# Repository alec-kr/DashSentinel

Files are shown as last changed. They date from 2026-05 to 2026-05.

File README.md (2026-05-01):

# 🚗 DashSentinel

**Real-time Driver Drowsiness Detection System with Embedded Feedback Interface**

<table align="center">
  <tr>
    <td align="center">
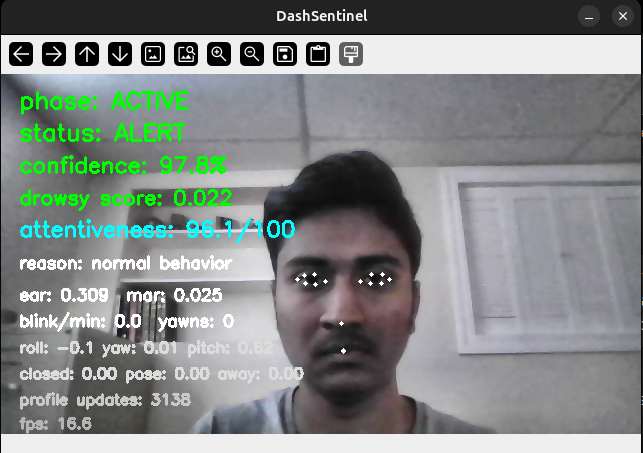
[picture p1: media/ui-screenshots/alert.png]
      <br>
      <b>Left:</b> Real-time facial tracking and attentiveness scoring
    </td>
    <td align="center">
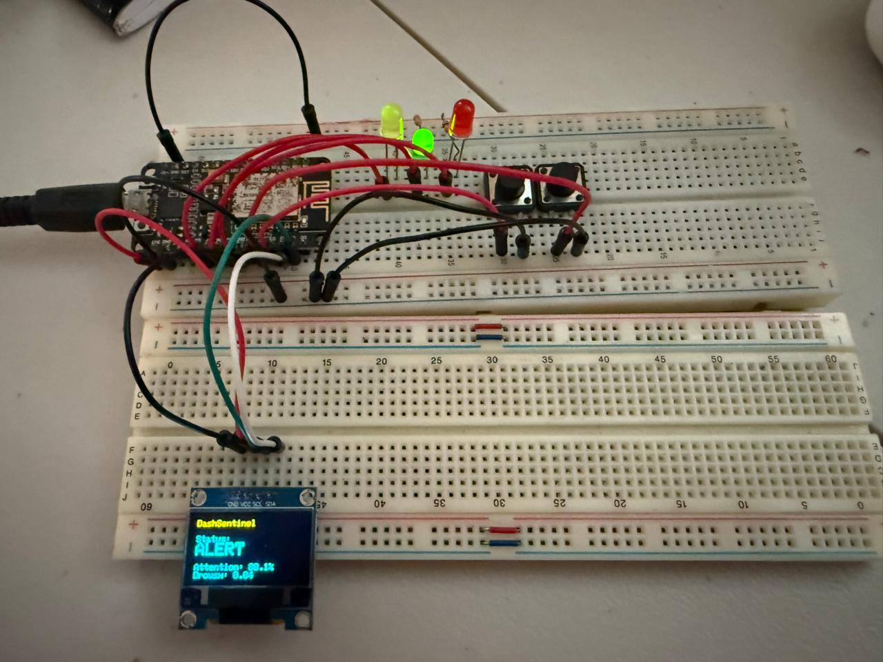
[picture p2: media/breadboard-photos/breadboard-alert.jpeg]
      <br>
      <b>Right:</b> ESP8266 hardware interface
    </td>
  </tr>
</table>

## Overview

The system combines:

- Computer Vision (MediaPipe / OpenCV) for facial feature extraction
- Machine Learning / Heuristics for drowsiness classification
- Embedded System (ESP8266) for real-time display and user interaction

It is designed as a prototype for a deployable driver safety product in fleets/personal use.

## Features
- Real-time face tracking and feature extraction
- Driver attentiveness scoring (%)
- Drowsiness detection based on:
    - eye closure patterns
    - yawning detection
    - attentiveness %

- OLED display output:
    - status (ALERT / WARNING / DROWSY)

- LED indicators:
    - 🟢 ALERT → solid green
    - 🟡 WARNING → blinking yellow
    - 🔴 DROWSY → fast blinking red

- Physical buttons:
    - Reset baseline (user-specific calibration)
    - Reset stats (data stored over-time)

## Tech Stack
### 💾 Software
- Python 3
- OpenCV
- MediaPipe
- TensorFlow (optional for model extensions)
- PySerial

### ⚙️ Hardware
- ESP8266 (NodeMCU)
- SSD1306 OLED (I2C, 128x64)
- Push buttons (x2)
- LEDs (red, yellow, green)
- Resistors (3x 330 ohms)

## 📁 Project Structure

```text

DashSentinel/
├── run_dashsentinel.py        # main entrypoint for execution
│
├── src/                       # core application logic
│   ├── app.py                 # main app orchestration
│   ├── features.py            # feature extraction (ear, yawning, etc.)
│   ├── model.py               # scoring / detection logic
│   └── serial.py              # esp8266 communication layer
│
├── DisplayModule/             # esp8266 firmware (platformio project)
│   └── src/
│       └── main.cpp           # oled, leds, buttons logic
│
├── nodemcu_carrier_pcb/       # hardware design (KiCad)
|
├── schematic/                 # schematic for all connections
│
├── data/                      # runtime-generated data
│   └── driver_profile.json    # user-specific baseline + stats
|
├── media/                     # Images showing the system in operation
│
├── requirements.txt           # python dependencies
└── README.md                  # project documentation

```

## Install requirements
```bash
pip install -r requirements.txt
```

## ▶️ Run the Project

### With UI and ESP8266 Interface
```bash
python3 run_dashsentinel.py --show-ui --draw-landmarks --enable-esp-serial --esp-port /dev/ttyUSB0
```

### Headless mode (logging enabled)
```bash
python3 run_dashsentinel.py --headless --log-csv --enable-esp-serial --esp-port /dev/ttyUSB0
```

### Optional flags (see ```src/cli.py``` for full list of options)
```bash
python3 run_dashsentinel.py --show-ui --draw-landmarks --refine-landmarks
```

## Startup Calibration
At startup:
- system learns user-specific facial metrics
- establishes baseline EAR and behavior

## Reset options
- Hardware button → reset baseline
- CLI flag → rebuild baseline at launch

```bash
python3 run_dashsentinel.py --show-ui --mirror --rebuild-baseline-on-start
```

## 🚀 Future Improvements
- Replace heuristic model with trained ML model
- Mobile app integration
- Full standalone embedded unit (dashcam form factor)

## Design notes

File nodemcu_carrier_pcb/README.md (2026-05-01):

## NodeMCU ESP-12E carrier board for DashSentinel external display/status module.

Features:
- Amica-style NodeMCU ESP-12E footprint, 22.86 mm / 0.9 in header spacing
- 4-pin I2C OLED connector: GND, VCC, SCL, SDA
- 3 status LEDs: green/yellow/red
- 2 push buttons
- Through-hole components for easy hand soldering

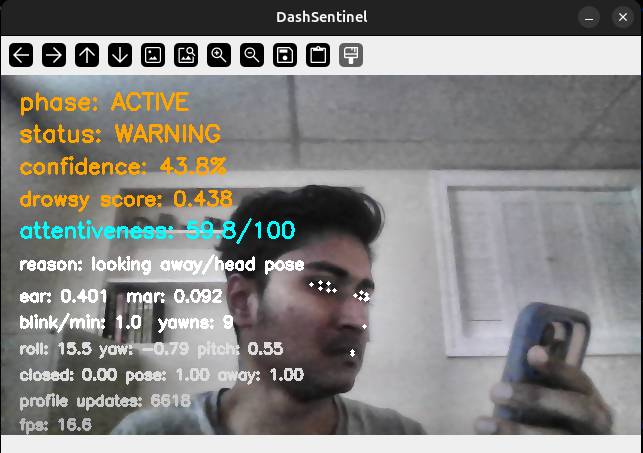
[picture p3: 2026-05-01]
media/ui-screenshots/warning-looking-away.png

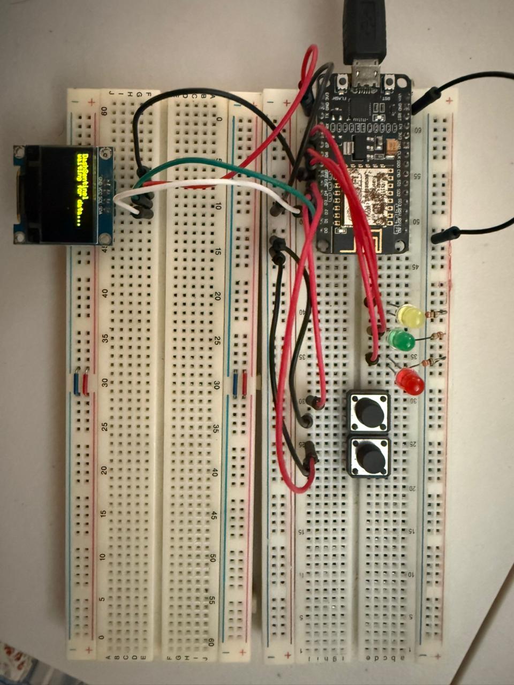
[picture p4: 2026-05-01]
media/breadboard-photos/breadboard-top-view.jpeg

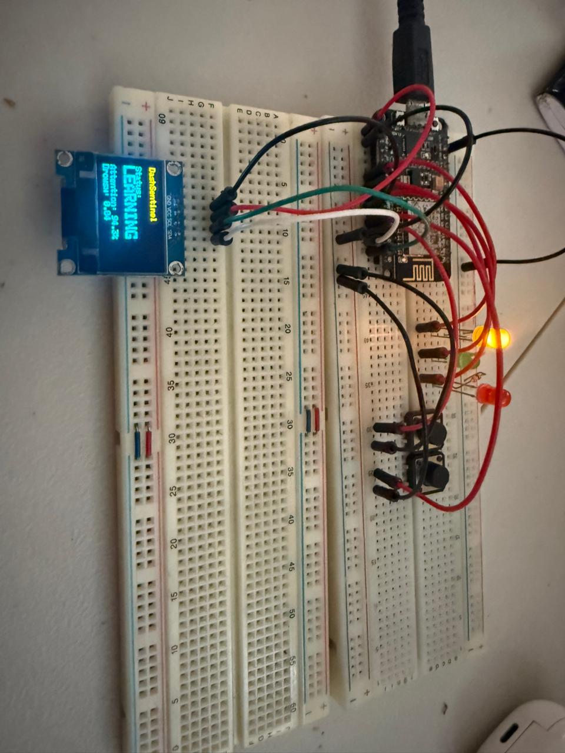
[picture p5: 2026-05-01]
media/breadboard-photos/breadboard-learning.jpeg

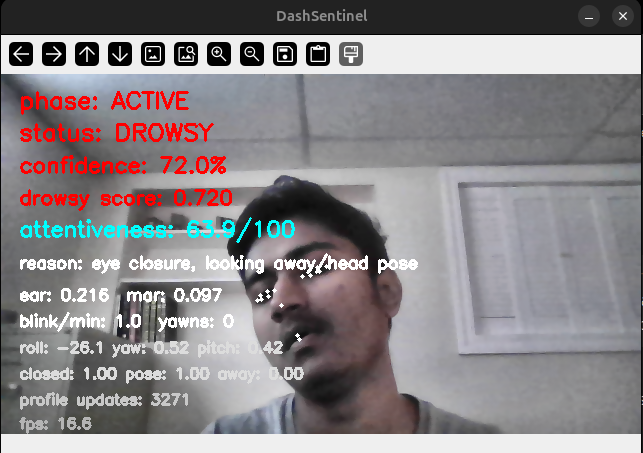
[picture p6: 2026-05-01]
media/ui-screenshots/drowsy-looking-away-eyes-closed.png

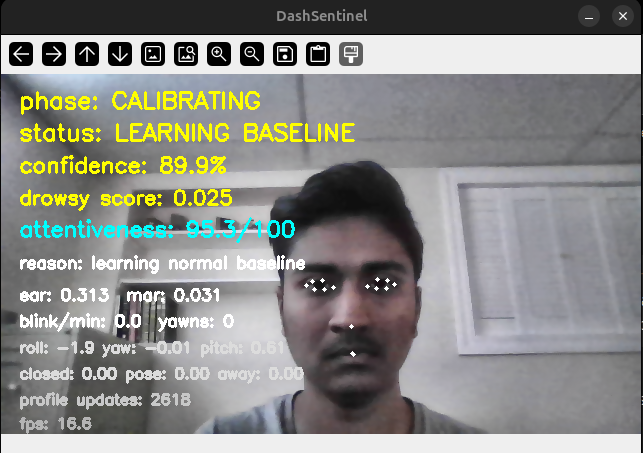
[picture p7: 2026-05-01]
media/ui-screenshots/learning_baseline.png

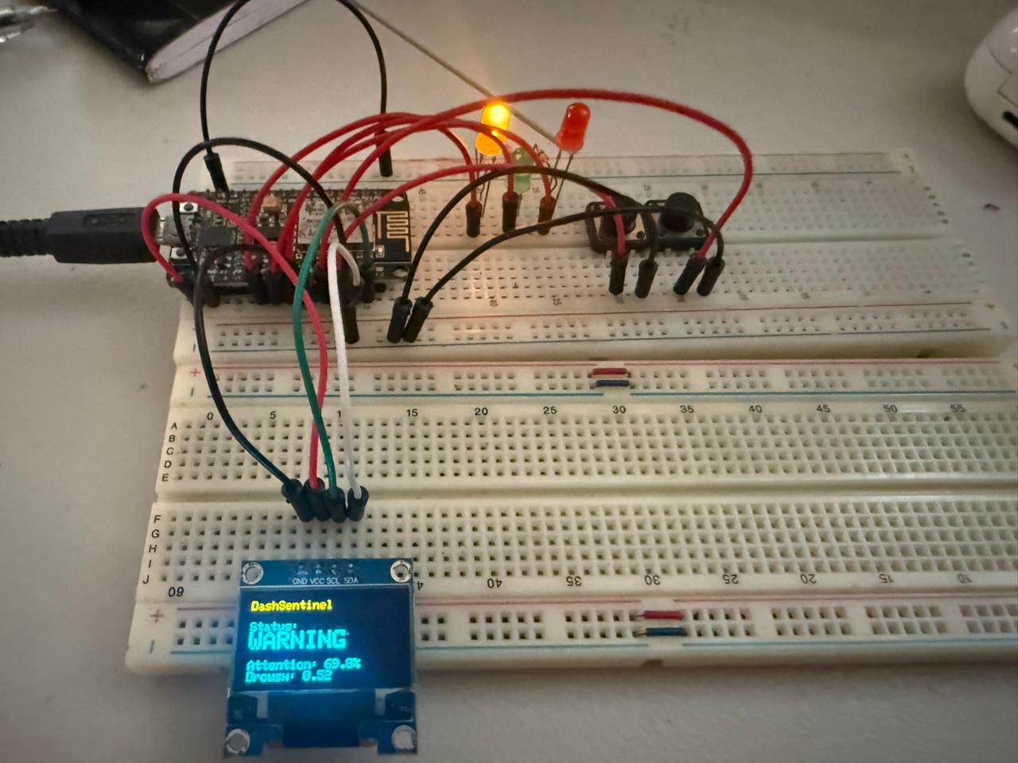
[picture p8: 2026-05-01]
media/breadboard-photos/breadboard-warning.jpeg

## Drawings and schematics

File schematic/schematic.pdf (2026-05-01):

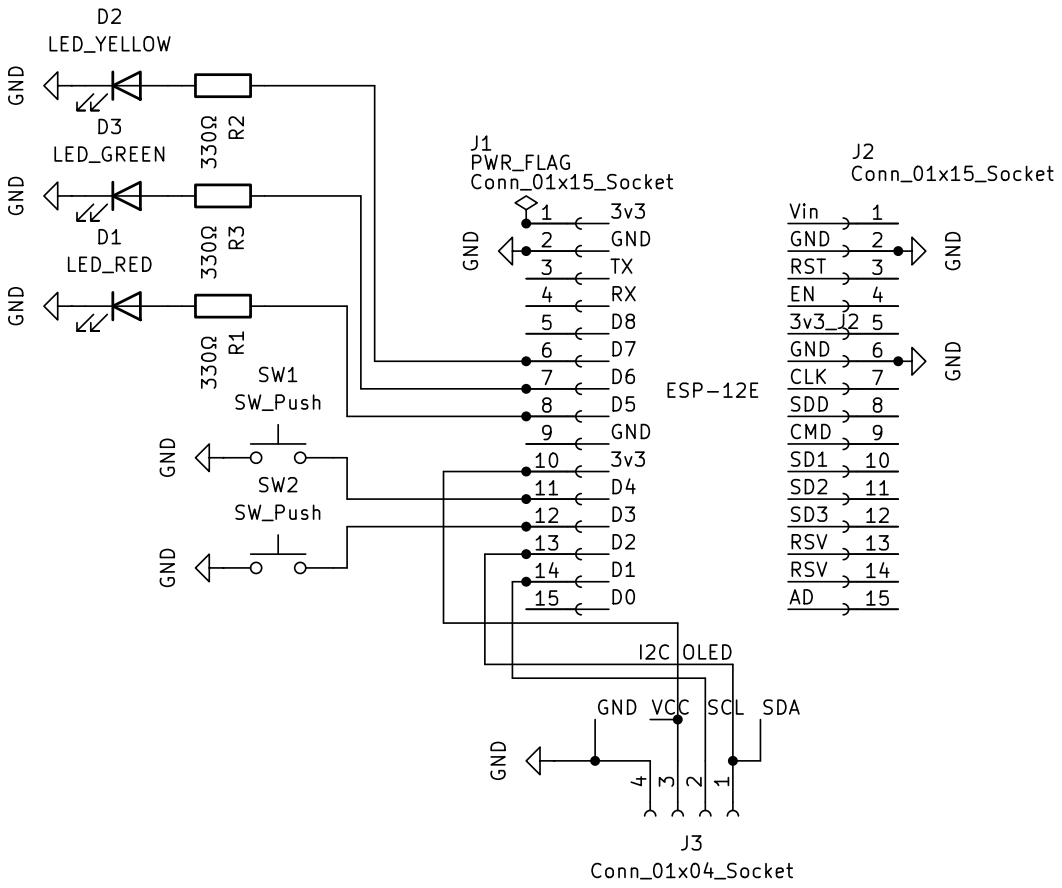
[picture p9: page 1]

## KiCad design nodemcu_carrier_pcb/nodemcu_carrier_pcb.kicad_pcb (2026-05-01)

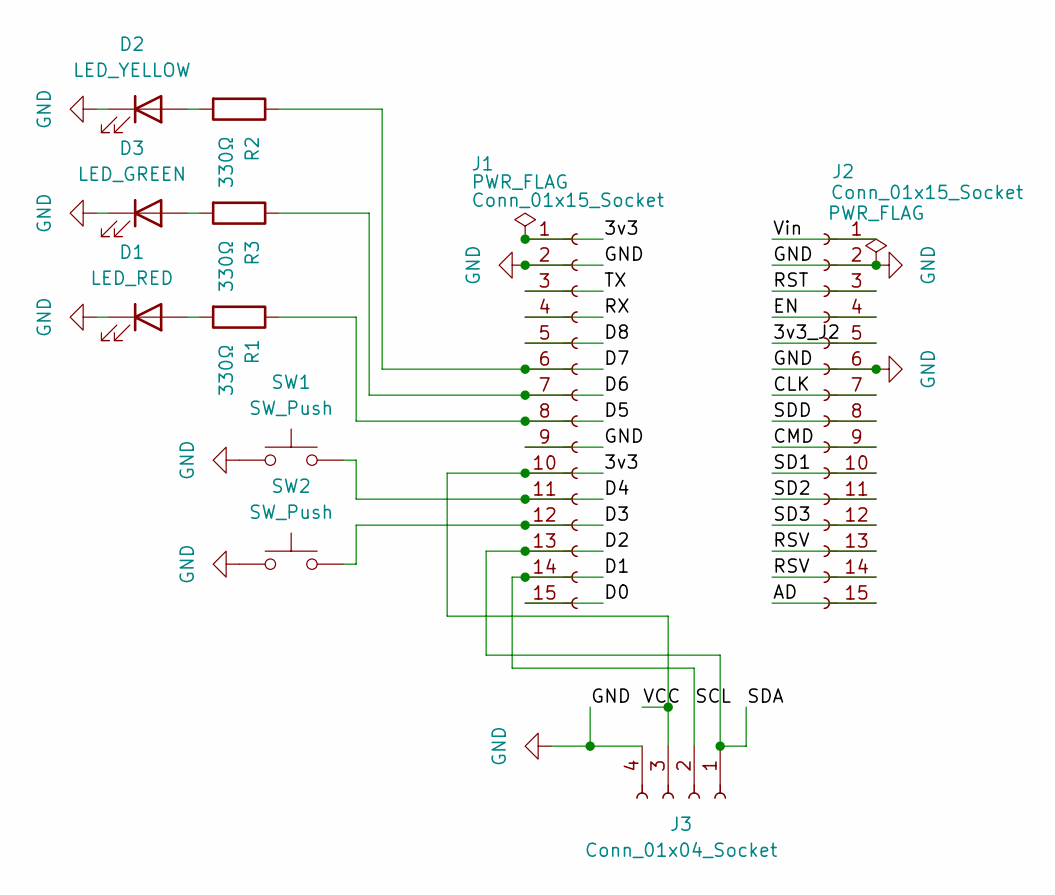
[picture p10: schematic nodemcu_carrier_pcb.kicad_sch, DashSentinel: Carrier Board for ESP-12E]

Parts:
D1: LED_RED; LED_D3.0mm
D2: LED_YELLOW; LED_D3.0mm
D3: LED_GREEN; LED_D3.0mm
J1, J2: Conn_01x15_Socket; PinSocket_1x15_P2.54mm_Vertical
J3: Conn_01x04_Socket; PinSocket_1x04_P2.54mm_Vertical
R1, R2, R3: 330Ω; R_Axial_DIN0207_L6.3mm_D2.5mm_P7.62mm_Horizontal
SW1, SW2: SW_Push; SW_PUSH_6mm

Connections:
/3v3: J1.1, J1.10, J3.3
/3v3_J2: J2.5
/AD: J2.15
/CLK: J2.7
/CMD: J2.9
/D0: J1.15
/D1: J1.14, J3.2
/D2: J1.13, J3.1
/D3: J1.12, SW2.2
/D4: J1.11, SW1.2
/D5: J1.8, R1.1
/D6: J1.7, R3.1
/D7: J1.6, R2.1
/D8: J1.5
/EN: J2.4
/RST: J2.3
/RSV: J2.13, J2.14
/RX: J1.4
/SD1: J2.10
/SD2: J2.11
/SD3: J2.12
/SDD: J2.8
/TX: J1.3
/Vin: J2.1
GND: D1.1 (K), D2.1 (K), D3.1 (K), J1.2, J1.9, J2.2, J2.6, J3.4, SW1.1, SW2.1
unnamed: D1.2 (A), R1.2
unnamed: D2.2 (A), R2.2
unnamed: D3.2 (A), R3.2

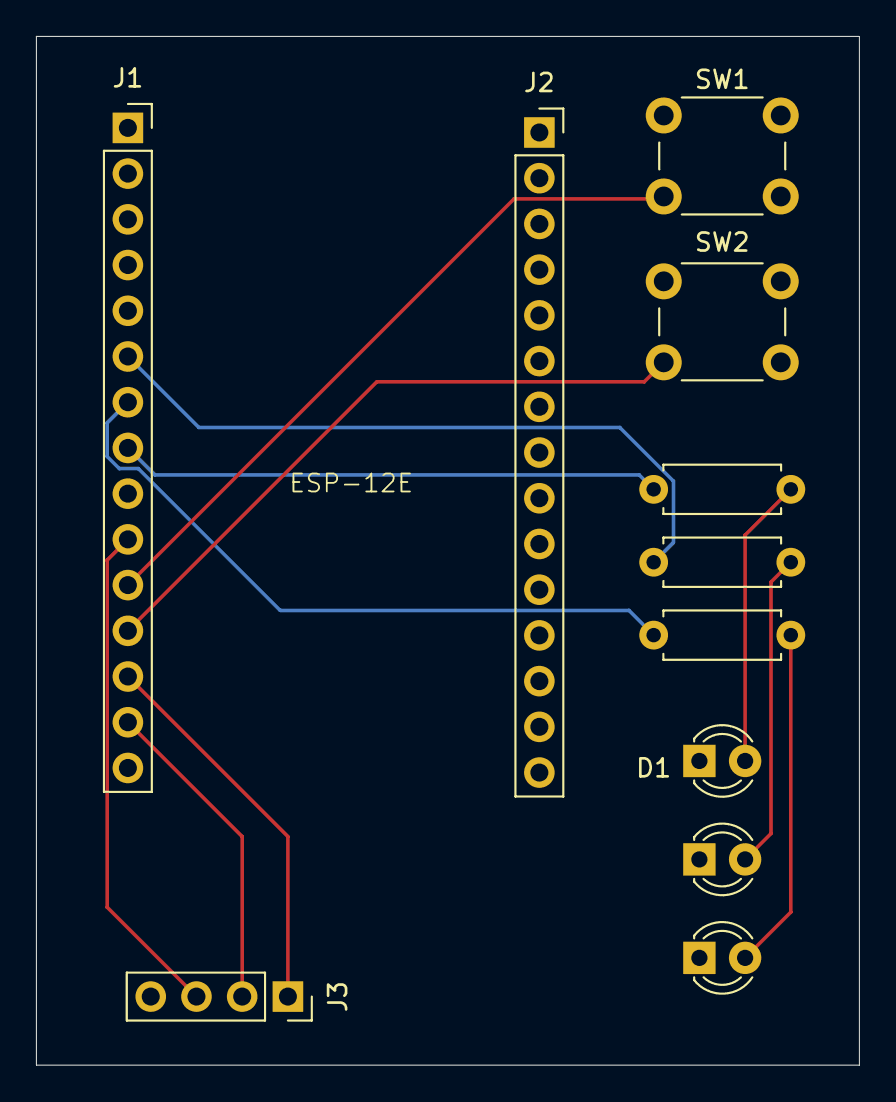
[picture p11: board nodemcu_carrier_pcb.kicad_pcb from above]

Board: 2 copper layers, 45.7 x 57.2 mm, 11 parts (0 on the bottom side), 13 nets.

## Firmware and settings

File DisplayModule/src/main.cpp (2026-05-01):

#include <Arduino.h>
#include <Wire.h>
// required for display
#include <Adafruit_GFX.h>
#include <Adafruit_SSD1306.h>

// init oled dimensions
#define SCREEN_WIDTH 128
#define SCREEN_HEIGHT 64
#define OLED_RESET -1

// define pins for buttons
#define BTN_RESET_BASELINE D3 // to reset the baseline for drowsiness detection
#define BTN_RESET_STATS D4 // to reset the drowsiness score and attentiveness score

#define redPin D5
#define greenPin D6
#define yellowPin D7

// i2c address for ssd1306
#define OLED_ADDR 0x3C

// display object
Adafruit_SSD1306 display(SCREEN_WIDTH, SCREEN_HEIGHT, &Wire, OLED_RESET);

// store current status and scores
String currentStatus = "NO DATA";
float attentiveness = 0.0;
float drowsyScore = 0.0;

// store last button states
bool lastBaselineState = HIGH;
bool lastStatBtnState = HIGH;

// store last button press times for debouncing
unsigned long lastBaselinePress = 0;
unsigned long lastStatBtnPress = 0;
const unsigned long debounceMs = 250;

// led state modes
enum LedMode {
  LED_OFF,
  LED_BASELINE,
  LED_ALERT,
  LED_WARNING,
  LED_DROWSY
};

LedMode ledMode = LED_OFF;
unsigned long lastLedToggle = 0;
bool ledOn = false;

// turn all leds off
void offLeds() {
  digitalWrite(redPin, LOW);
  digitalWrite(greenPin, LOW);
  digitalWrite(yellowPin, LOW);
}

// change led behavior based on current driver status
void setLedMode(LedMode mode) {
  if (ledMode == mode) {
    return;
  }

  ledMode = mode;
  ledOn = false;
  lastLedToggle = millis();

  offLeds();

  if (ledMode == LED_ALERT) {
    digitalWrite(greenPin, HIGH);
  }
  else if (ledMode == LED_BASELINE) {
    digitalWrite(yellowPin, HIGH);
  }
}

// update blinking leds without blocking button or serial reads
void updateLeds() {
  if (ledMode == LED_ALERT || ledMode == LED_OFF || ledMode == LED_BASELINE) {
    return;
  }

  unsigned long now = millis();

  int activePin = yellowPin;
  unsigned long interval = 250;

  if (ledMode == LED_WARNING) {
    activePin = yellowPin;
    interval = 250;
  } 
  else if (ledMode == LED_DROWSY) {
    activePin = redPin;
    interval = 100;
  }

  if (now - lastLedToggle >= interval) {
    lastLedToggle = now;
    ledOn = !ledOn;

    offLeds();
    digitalWrite(activePin, ledOn ? HIGH : LOW);
  }
}

// show current status and scores on the display
void drawDisplay() {
  display.clearDisplay();

  display.setTextColor(SSD1306_WHITE);

  display.setTextSize(1);
  display.setCursor(0, 0);
  display.print("DashSentinel");

  display.setCursor(0, 16);
  display.print("Status:");

  display.setTextSize(2);
  display.setCursor(0, 24);

  if (currentStatus == "LEARNING BASELINE") {
    display.print("LEARNING");
  }
  else {
    display.println(currentStatus);
  }

  display.setTextSize(1);
  display.setCursor(0, 48);
  display.print("Attention: ");
  display.print(attentiveness, 1);
  display.print("%");

  display.setCursor(0, 57);
  display.print("Drowsy: ");
  display.print(drowsyScore, 2);

  display.display();
}

// parse incoming serial data once in format "status,attentiveness,drowsyScore"
void parseLine(String line) {
  line.trim();

  int firstComma = line.indexOf(',');
  int secondComma = line.indexOf(',', firstComma + 1);

  if (firstComma < 0 || secondComma < 0) {
    return;
  }

  currentStatus = line.substring(0, firstComma);
  attentiveness = line.substring(firstComma + 1, secondComma).toFloat();
  drowsyScore = line.substring(secondComma + 1).toFloat();

  if (currentStatus == "ALERT") {
    setLedMode(LED_ALERT);
  }
  else if (currentStatus == "LEARNING BASELINE") {
    setLedMode(LED_BASELINE);
  }
  else if (currentStatus == "WARNING") {
    setLedMode(LED_WARNING);
  } 
  else if (currentStatus == "DROWSY") {
    setLedMode(LED_DROWSY);
  } 
  else {
    setLedMode(LED_OFF);
  }

  drawDisplay();
}

// check button states and print to serial if pressed
void checkButtons() {
  bool baselineState = digitalRead(BTN_RESET_BASELINE);
  bool statBtnState = digitalRead(BTN_RESET_STATS);
  unsigned long now = millis();

  if (lastBaselineState == HIGH && baselineState == LOW && (now - lastBaselinePress > debounceMs)) {
    Serial.println("BTN_RESET_BASELINE");
    lastBaselinePress = now;
  }

  if (lastStatBtnState == HIGH && statBtnState == LOW && (now - lastStatBtnPress > debounceMs)) {
    Serial.println("BTN_RESET_STATS");
    lastStatBtnPress = now;
  }

  lastBaselineState = baselineState;
  lastStatBtnState = statBtnState;
}

void setup() {
  // using internal pullup resistors for buttons
  // so they read high when not pressed and low when pressed
  pinMode(BTN_RESET_BASELINE, INPUT_PULLUP);
  pinMode(BTN_RESET_STATS, INPUT_PULLUP);
  pinMode(redPin, OUTPUT);
  pinMode(greenPin, OUTPUT);
  pinMode(yellowPin, OUTPUT);

  offLeds();

  Serial.begin(115200);
  Wire.begin();

  if (!display.begin(SSD1306_SWITCHCAPVCC, OLED_ADDR)) {
    while (true) {
      delay(1000);
    }
  }

  display.clearDisplay();
  display.setTextColor(SSD1306_WHITE);
  display.setTextSize(1);
  display.setCursor(0, 0);
  display.println("DashSentinel");
  display.println("waiting for data...");
  display.display();
}

void loop() {
  checkButtons();

  if (Serial.available()) {
    String line = Serial.readStringUntil('\n');
    parseLine(line);
  }

  updateLeds();
}

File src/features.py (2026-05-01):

"""handles feature extraction from facial landmarks"""

import time
from collections import deque

import cv2
import numpy as np

from .constants import (
    LEFT_CHEEK,
    LEFT_EYE,
    LEFT_EYE_OUTER,
    LEFT_MOUTH,
    MOUTH_BOTTOM,
    MOUTH_TOP,
    NOSE_TIP,
    RIGHT_CHEEK,
    RIGHT_EYE,
    RIGHT_EYE_OUTER,
    RIGHT_MOUTH,
)
from .utils import clamp, euclidean

def get_point(landmarks, idx, w, h):
    """convert landmark to pixel coordinates"""
    lm = landmarks[idx]
    return np.array([lm.x * w, lm.y * h], dtype=np.float32)

def eye_aspect_ratio(landmarks, eye_indices, w, h):
    """Get eye aspect ratio for given eye landmarks."""
    pts = [get_point(landmarks, idx, w, h) for idx in eye_indices]

    if len(pts) != 6:
        return 0.0

    p1, p2, p3, p4, p5, p6 = pts
    vertical_1 = euclidean(p2, p6)
    vertical_2 = euclidean(p3, p5)
    horizontal = euclidean(p1, p4)

    if horizontal == 0:
        return 0.0

    return (vertical_1 + vertical_2) / (2.0 * horizontal)

def mouth_aspect_ratio(landmarks, w, h):
    """get mouth aspect ratio for given mouth landmarks"""
    top = get_point(landmarks, MOUTH_TOP, w, h)
    bottom = get_point(landmarks, MOUTH_BOTTOM, w, h)
    left = get_point(landmarks, LEFT_MOUTH, w, h)
    right = get_point(landmarks, RIGHT_MOUTH, w, h)

    vertical = euclidean(top, bottom)
    horizontal = euclidean(left, right)

    # return 0 to avoid division by zero and indicate mouth is closed
    if horizontal == 0:
        return 0.0

    # higher ratio indicates mouth is more open.
    return vertical / horizontal

def estimate_head_pose(landmarks, w, h):
    """estimate head pose: roll, yaw, and pitch."""
    points = {
        "left_eye": get_point(landmarks, LEFT_EYE_OUTER, w, h),
        "right_eye": get_point(landmarks, RIGHT_EYE_OUTER, w, h),
        "nose": get_point(landmarks, NOSE_TIP, w, h),
        "mouth_top": get_point(landmarks, MOUTH_TOP, w, h),
        "mouth_bottom": get_point(landmarks, MOUTH_BOTTOM, w, h),
        "left_cheek": get_point(landmarks, LEFT_CHEEK, w, h),
        "right_cheek": get_point(landmarks, RIGHT_CHEEK, w, h),
    }

    eye_center = (points["left_eye"] + points["right_eye"]) / 2.0
    mouth_center = (points["mouth_top"] + points["mouth_bottom"]) / 2.0

    dx = points["right_eye"][0] - points["left_eye"][0]
    dy = points["right_eye"][1] - points["left_eye"][1]
    roll_deg = np.degrees(np.arctan2(dy, dx)) if abs(dx) > 1e-6 else 0.0

    left_dist = euclidean(points["nose"], points["left_cheek"])
    right_dist = euclidean(points["nose"], points["right_cheek"])
    total_dist = left_dist + right_dist

    yaw_ratio = 0.0
    if total_dist > 1e-6:
        yaw_ratio = (right_dist - left_dist) / total_dist

    face_vertical = max(mouth_center[1] - eye_center[1], 1e-6)
    pitch_ratio = (points["nose"][1] - eye_center[1]) / face_vertical

    return float(roll_deg), float(yaw_ratio), float(pitch_ratio)

def enhance_lighting(frame):
    """enhance lighting and contrast of the input frame using CLAHE and gamma correction"""
    # convert image color space (bgr <-> rgb/lab)
    lab = cv2.cvtColor(frame, cv2.COLOR_BGR2LAB)
    l, a, b = cv2.split(lab)
    clahe = cv2.createCLAHE(clipLimit=2.0, tileGridSize=(8, 8))
    l = clahe.apply(l)
    merged = cv2.merge((l, a, b))

    # convert image color space (bgr <-> rgb/lab)
    enhanced = cv2.cvtColor(merged, cv2.COLOR_LAB2BGR)
    gamma = 1.12
    table = np.array(
        [
            (i / 255.0) ** (1.0 / gamma) * 255 for i in np.arange(256)
        ]
    ).astype("uint8")
    enhanced = cv2.LUT(enhanced, table)
    enhanced = cv2.bilateralFilter(enhanced, 5, 35, 35)
    return enhanced

# pylint: disable=too-many-instance-attributes
class FeatureExtractor:
    """feature extractor for all facial features"""

    # initialize thresholds and state for feature extraction
    def __init__(self, ear_threshold=0.23, yawn_mar_threshold=0.4, yawn_frames_threshold=30):
        # compute eye aspect ratio to detect eye closure
        self.ear_threshold = ear_threshold
        self.yawn_mar_threshold = yawn_mar_threshold
        self.yawn_frames_threshold = yawn_frames_threshold

        # compute eye aspect ratio to detect eye closure
        self.ear_history = deque(maxlen=10)
        self.blink_timestamps = deque(maxlen=90)
        self.eye_closed = False
        self.closed_frames = 0
        self.mouth_open_frames = 0
        self.last_yawn_time = 0.0
        self.yawn_count = 0

        # for head motion
        self.mar_history = deque(maxlen=30)
        self.roll_history = deque(maxlen=30)
        self.yaw_history = deque(maxlen=30)
        self.pitch_history = deque(maxlen=30)

        self.bad_pose_frames = 0
        self.look_away_frames = 0
        self.head_tilt_frames = 0
        self.head_back_frames = 0

    def reset(self):
        """reset all states/counters for a new session"""
        self.ear_history.clear()
        self.blink_timestamps.clear()
        self.mar_history.clear()
        self.roll_history.clear()
        self.yaw_history.clear()
        self.pitch_history.clear()


        self.eye_closed = False
        self.closed_frames = 0
        self.mouth_open_frames = 0
        self.bad_pose_frames = 0
        self.look_away_frames = 0
        self.head_tilt_frames = 0
        self.head_back_frames = 0

    # pylint: disable=too-many-locals,too-many-branches,too-many-statements
    def extract(self, landmarks, w, h):
        """compute features from face landmarks (ear, mar, blink, pose)"""
        # compute eye aspect ratio to detect eye closure
        left_ear = eye_aspect_ratio(landmarks, LEFT_EYE, w, h)
        right_ear = eye_aspect_ratio(landmarks, RIGHT_EYE, w, h)
        ear = (left_ear + right_ear) / 2.0
        self.ear_history.append(ear)

        # compute eye aspect ratio to detect eye closure
        ear_smoothed = sum(self.ear_history) / len(self.ear_history)

        # current timestamp used for fps or timing logic
        now = time.time()

        # if the smoothed EAR is below the threshold, consider the eye closed
        if ear_smoothed < self.ear_threshold:
            if not self.eye_closed:
                self.eye_closed = True
            self.closed_frames += 1
        else:
            if self.eye_closed:
                self.blink_timestamps.append(now)
                self.eye_closed = False
            self.closed_frames = max(0, self.closed_frames - 2)

        # remove old blink timestamps beyond 60 seconds to compute recent blink rate
        while self.blink_timestamps and now - self.blink_timestamps[0] > 60:
            self.blink_timestamps.popleft()
        blink_rate = float(len(self.blink_timestamps))
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

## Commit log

2026-04-18 Update README with testing hardware details
    Added information about testing on Intel N100 and NVIDIA Jetson Orin Nano.
2026-04-20 Update tested devices in README
2026-04-22 Update README with MediaPipe requirements
    Added note about MediaPipe requirements for Raspberry Pi.
2026-04-29 added button functionality and reset logic
    [app.py, features.py, main.cpp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]
2026-04-30 Added comments and fixed readme
    [app.py, cli.py, features.py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]
2026-04-30 Fixed whitespace and long lines in app.py
    [app.py]
2026-04-30 Fixed some pylint issues
    [app.py, cli.py, features.py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]
2026-04-30 fixing mediapipe pylint issue
    [app.py]
2026-04-30 Added logic for 3 LEDs
2026-05-01 Added support for LEDs
2026-05-01 Add esp12e carrier board hardware design
    [nodemcu_carrier_pcb-B_Cu.gbr, nodemcu_carrier_pcb-B_Mask.gbr, nodemcu_carrier_pcb-B_Silkscreen.gbr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]
2026-05-01 Update kicad schema
2026-05-01 Added screenshots and schematics
2026-05-10 Rename driver_profile.json to sample_driver_profile.json
    Changing filename to prevent users from having to rebuild baseline on first run.
